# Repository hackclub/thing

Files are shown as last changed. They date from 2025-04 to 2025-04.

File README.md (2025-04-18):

<picture>
  <source media="(prefers-color-scheme: dark) and (max-width: 960px)" srcset="./thing.png">
  <source media="(prefers-color-scheme: dark) and (min-width: 961px)" width="50%" srcset="./thing.png">

  <source media="(prefers-color-scheme: light) and (max-width: 960px)" srcset="./thing-light.png">
  <source media="(prefers-color-scheme: light) and (min-width: 961px)" width="50%" srcset="./thing-light.png">

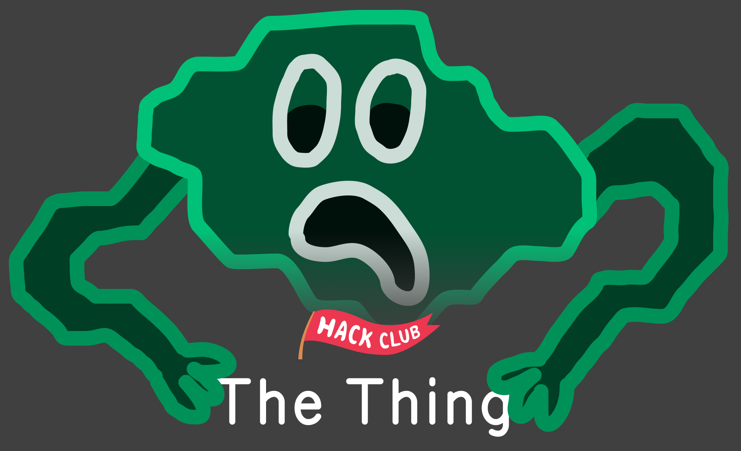
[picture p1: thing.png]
The thing
  
</picture>

Hey! Welcome to **The Thing**!

## Hey, what is this thing?
Have you seen those 80-part Swiss Army knives? I want us to make a PCB with that level of esotericism; a sprawling, over-the-top monstrosity.

Many Hack Clubbers will add a tool or something to the same PCB consecutively, and at the end I'll get \~10 made and send them off to some people you may or may not have seen on YouTube...
(and if you find me at a hackathon and you've added a subsystem to the board you may end up with one too (prob limited to 1 or 2)).

It'll end when 100 subsystems have been added or nobody adds a component for a week. Happy hacking!

## Current thing:
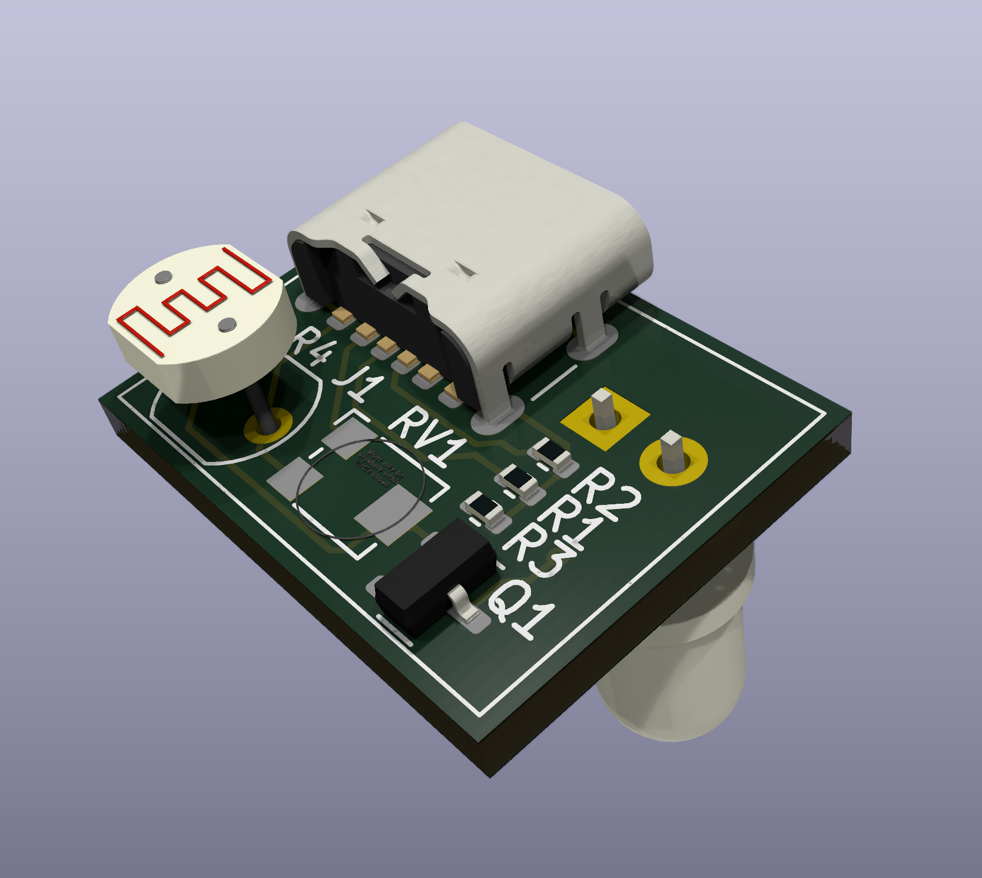
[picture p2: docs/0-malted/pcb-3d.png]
3D PCB


## How will it work?
* People will take turns adding their subsystem.
* Each person will get 2 days. If it's not merged after exactly 2 days, you'll be put at the back of the queue for another go and it'll be handed off to the next person. **I'll DM you a day or two before it's your turn to make sure you're ready. If you don't respond you might be skipped.**
* Merging requires me to be reasonably sure it'll work.

## What should my submission include?
* In the `/docs` directory, add a folder titled `IDX-USERNAME`, where `IDX` is your number in line, and `USERNAME` is your GitHub username.
  * For example, I'm the first person to go, so my folder is named `0-malted`.
  * In your folder, you'll need;
    * `doc.md`: Your writeup. Include detail about your subsystem! How you designed it, your calculations, tests, everything. Don't use an LLM, make it interesting, tell me a story!! :D
    * `pcb.png`: A screenshot of the PCB in Kicad's PCB editor, showing the entire PCB.
    * `pcb-3d.png`: Switch to View > 3D viewer and select "Render current view using raytracing". Again, we want to see the whole board!
    * `schematic.png`: A screenshot of the whole board's schematic.
    * `cad.png` **(OPTIONAL)**: If someone designs an enclosure or something (wink wink nudge nudge), show me a screenshot of it. You only need to do this if you've changed it.
    * `bom.csv`: Your bill of materials. Create and edit this manually. The price should be that of a single part (regardless of your `quantity`, **on the line item for 100 pieces**. It should be in USD without a dollar symbol.
      * For an exemplar BoM check mine out: `/docs/0-malted/bom.csv`. There's a template at `/docs/bom-template.csv`.
  * Make your schematic as complete as possible! When you double click your components you can add datasheets to help out others who might need to tie into your circuit or something in the future.

## Constraints
* Use Kicad `9.0.x`. Apparently, our project will be corrupted if we're on differing versions.
* Each BoM must not exceed $5 in parts. Assume 3D printing is free. If you have an especially cool idea I could be convinced to double it on a case-by-case basis :)
* Please strongly bias for parts in stock on Digikey.

## Tips
Finding parts can be tricky. Here's how I found the USB-C receptable I used in my circuit;
  1. Added a symbol to my schematic. I only wanted it for the 5V rail, so I found a symbol with the description "*USB Power-Only 6P Type-C Receptacle connector*". Seems okay.
  2. Opened the *footprint editor* and searched for "*usb c receptacle 6p*" (6P meaning it has 6 pins, which is minimal). I found a footprint named "*USB_C_Receptacle_GCT_USB4125-xx-x_6P_TopMnt_Horizontal*", which looked good. I liked the footprint because it had through-hole shield pins, meaning it would be less likely to be ripped off the board when pulling on it. The only other footprint which actually had 6 pins didn't have the through-hole shield.
  3. I searched on the internet for "*USB4125*". I found the [page from the manufacturer](https://gct.co/connector/usb4125) (GCT), which had links to Mouser and Digikey, amongst others. Heaven. It was slightly cheaper on Mouser so I went with that. It's comforting that it says *21230 In stock*.
  4. I double click on my component, click the library icon at the end of the "Footprint" table row, and searched for "*gct usb 4125*". Assigned it. Placed it on my PCB, and added it to my BoM! All done.

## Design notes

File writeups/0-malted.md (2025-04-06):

My subsystem is a nightlight that turns an LED on when an LDR (light-dependent resistor) detects it's dark. It's powered via a USB-C 5v rail.

When it's light, the resistance of the LDR is low, meaning the voltage at the base of the transistor is low, so the transistor is switched off, meaning the LED is not lit.
When it's dark, the resistance of the LDR is high, meaning the voltage at the base of the transistor is high, so the transistor switches on, allowing current to flow from the collector to emmitter, turning it on, allowing current to flow through the LED, through R3 to ground, lighting it up.

---

Alex sent me [this](https://cdn.sparkfun.com/datasheets/Sensors/LightImaging/SEN-09088.pdf) datasheet for the GL5528 LDR so that's what I'm going to work off - it's very generic. I'm also using a generic BJT NPM (Mouser has ~200k of [these](https://www.mouser.com/datasheet/2/308/BC550_D-1802078.pdf) in stock so that's what I'll go off, although none of the following is specific to this component.)

I don't know how much 100 lux or 1 lux is, but going by the diagram I'm going to assume that 100 lux is "bright" and 1 lux is "dark".
This means that when it's bright, the LDR will have a resistance of ~3kΩ, and when it's dark the LDR will have a resistance of 70kΩ.

When it's light, I want the LED to be off. This means the transistor must be off, meaning Vb must be < 0.7V.
So, using the voltage divider equation `Vout = R2 / (R1 + R2) * Vin`, and a voltage under 0.7V, say, 0.2V as our Vbe target, we calculate R1 to be 72kΩ, as shown below.

```
0.2 = 3k / (R1 + 3k) * 5
0.04 = 3k / (R1 + 3k)
0.04 * R1 + 120 = 3k
0.04 * R1 = 2.88k
R1 = 2.88k / 0.04
R1 = 72k
```

Great. Now, let's check to make sure that when it's dark, Vbe will be > 0.7V by plugging 72kΩ into R1 (keeping in mind R2 is now 70kΩ);

```
Vout = 70k / (72k + 70k) * 5
Vout ~= 2.5V
```

Yay! The output of our voltage divider is > 0.7V, so it's going to switch the transistor on, meaning the LED will light up.

Now let's calculate R3. Without it, we'd be dumping 5V across our poor little LED.

I've selected a [nice little amber LED to use](https://www.mouser.com/datasheet/2/678/av02-1532en_ds_hlmp-wl02_2014-08-20-1827901.pdf). Nora said amber makes for a good nightlight colour. The datasheet says it has a 2.02V drop. BJTs typically drop 0.2V. So, the voltage our R3 needs to drop is (5 - (2.02 + 0.2)) = 2.78V`.

Our LED datasheet says the LED should typically be operated between 10mA and 30mA, so let's pick 20mA. This means R3 needs to be the following;

```
V = IR
2.78 = 0.02 * R
R = 2.78 / 0.02
R = 139
```

R3 needs to be 139Ω. There's no 139Ω resistor in the [E24 series](https://asenergi.com/pdf/resistors/standard-resistor-values-e24.pdf) so I'll pick a 150Ω resistor which is close enough!

---

Footnote, it's been so long since I've done calculations like this that I forgot to make sure Ic is high enough to saturate the transistor. It's *JUST* about there. It's not going to kneecap the subsystem as far as I can tell so I won't rejig the voltage divider.

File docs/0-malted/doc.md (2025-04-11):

My subsystem is a nightlight that turns an LED on when an LDR (light-dependent resistor) detects it's dark. It's powered via a USB-C 5v rail.

When it's light, the resistance of the LDR is low, meaning the voltage at the base of the transistor is low, so the transistor is switched off, meaning the LED is not lit.
When it's dark, the resistance of the LDR is high, meaning the voltage at the base of the transistor is high, so the transistor switches on, allowing current to flow from the collector to emmitter, turning it on, allowing current to flow through the LED, through R<sub>3</sub> to ground, lighting it up.

---

Firstly, I need a power source. It's 2025, so I want to plug in a USB-C cable. I looked for a while and found this. It needs 2 5k1Ω resistors on the *CC* lines, which are for negotiating power. If you wanted to get serious you can negotiate up to like 20V and >3A IIRC but for this 5V is all I want. [A Hack Club alum—Hugo—made an amazing reference guide for USB-C power lines a couple of years ago](https://www.hugohu.me/media/USB-C.Primer.pdf), in which it says to use 5100Ω resistors on both CC1 and CC2 lines to be compatible with fancy USB-C cables and bricks. [Here's the 5k1Ω resistor I chose.](https://www.digikey.com/en/products/detail/yageo/RC0402FR-075K1L/726624), and here's the USB-C receptable I found! I wrote my thought process leading to finding this specific component at the bottom of the readme.

I searched for an LDR on Digikey and found the [PDV-P8103](https://www.digikey.com/en/products/detail/advanced-photonix/PDV-P8103/480610). Generic photoresistor. Great! According to the datasheet, is resistance is 0.5MΩ in the dark and 16k-33kΩ in the light.

> I originally tried to use an [NPN BJT](https://en.wikipedia.org/wiki/Bipolar_junction_transistor) (in writing this doc I kept typing NPM - the rot consumes) that looked good, but I found out that my base current would be too low to drive my LED because of the high voltage divider resistor values. I switched to a MOSFET.

I found a MOSFET on Digikey that has a footprint in Kicad; the [T2N7002AK](https://www.digikey.com/en/products/detail/toshiba-semiconductor-and-storage/T2N7002AK-LM/5298028). Looking at [the datasheet](https://toshiba.semicon-storage.com/info/docget.jsp?did=29712&prodName=T2N7002AK), we can tell V<sub>GSₜₕ</sub>—or the voltage drop between the gate and the source when the MOSFET switches—is between 1.1V and 2.1V. Normally, I would calculate the resistor value to be exactly correct. But since I can't know how bright users' rooms will be at night, I'm going to opt for a trimmer potentiometer so they can calibrate it themselves. 100kΩ max should be enough. The trimpot I'm going to use is the [TC33X-2-104E](https://www.digikey.com/en/products/detail/bourns-inc/TC33X-2-104E/612859).

Now let's calculate the value for R<sub>3</sub>. Without it, we'd be dumping ~5V across our little LED.

According to the MOSFET's datasheet, the drop across the drain and source (V<sub>DS</sub>) looks like ~100mV when I<sub>D</sub> is ~20mA and V<sub>GS</sub> is ~4V. The graph resolution down there is quite low so this is approximate but since it's proportionally such a small voltage it doesn't matter too much anyway.
Id-Vds graph for the T2N7002AK MOSFET

I've selected a [nice little amber LED to use](https://www.mouser.com/datasheet/2/678/av02-1532en_ds_hlmp-wl02_2014-08-20-1827901.pdf). Nora said amber makes for a good nightlight colour. The datasheet says it has a 2.02V drop. So, combined with the MOSFET's V<sub>DS</sub>, the voltage our R<sub>3</sub> needs to drop is (5 - (2.02 + 0.1)) = 2.88V`.

Our LED datasheet says the LED should typically be operated between 10mA and 30mA, so let's pick 20mA. This means R<sub>3</sub> needs to be the following;

```
V = IR
2.88 = 0.02 * R
R = 2.88 / 0.02
R = 144
```

R<sub>3</sub> needs to be 144Ω. There's no 144Ω resistor in the [E24 series](https://asenergi.com/pdf/resistors/standard-resistor-values-e24.pdf) so I'll pick a 150Ω resistor which is close enough!

I'm picking a surface-mounted resistor with a power rating of 1/16W, which is less than what I could dump across a through-hole. Let's check to see if how I want to use it would be in spec. This can be checked with the power law.

```
P = IV
1/16 = 20mA * V
V = (1/16) / 0.02
V ‎ = 3.125
```

So, with the current load, the resistor can drop a max of 3.125V. This is okay, because in its current configuration it's only dropping 2.88V.

The total of my BoM is only ~$1.38 :) nice

> P.S. I'm pretty proud I got my pcb traced in a single layer! Routing everything again and again was very theraputic.

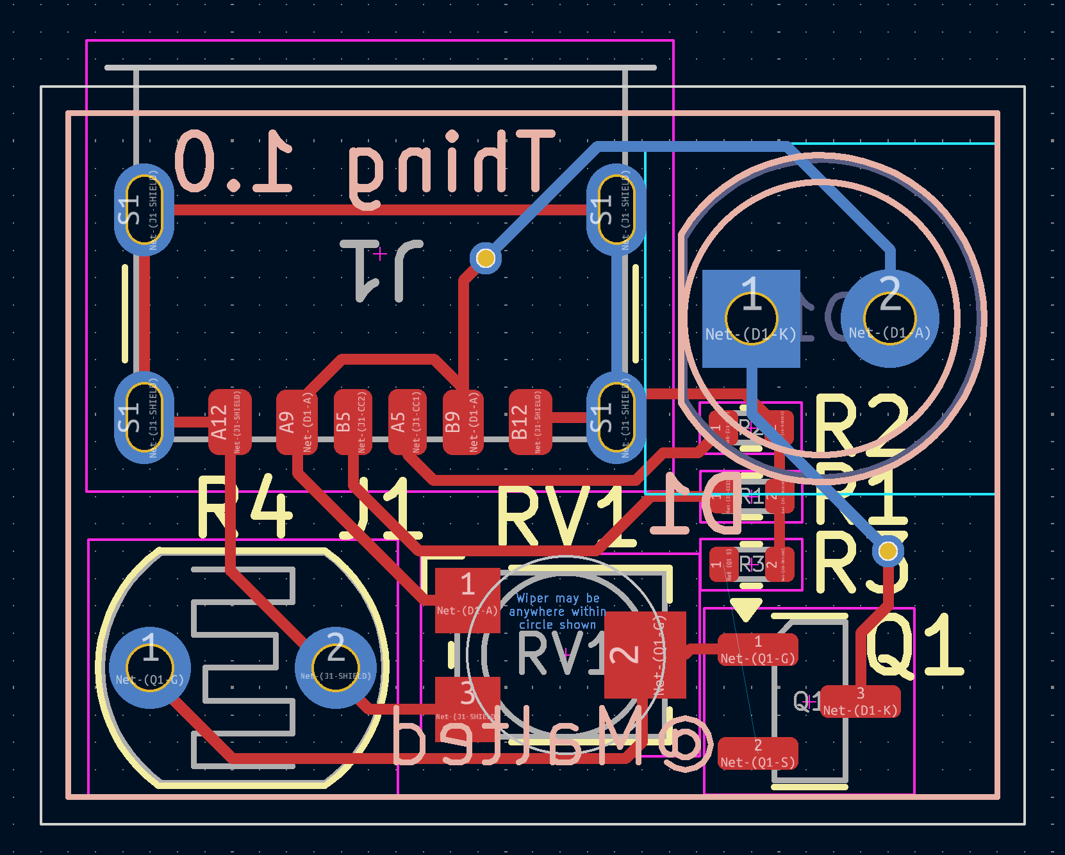
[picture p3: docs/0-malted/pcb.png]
PCB

3D PCB
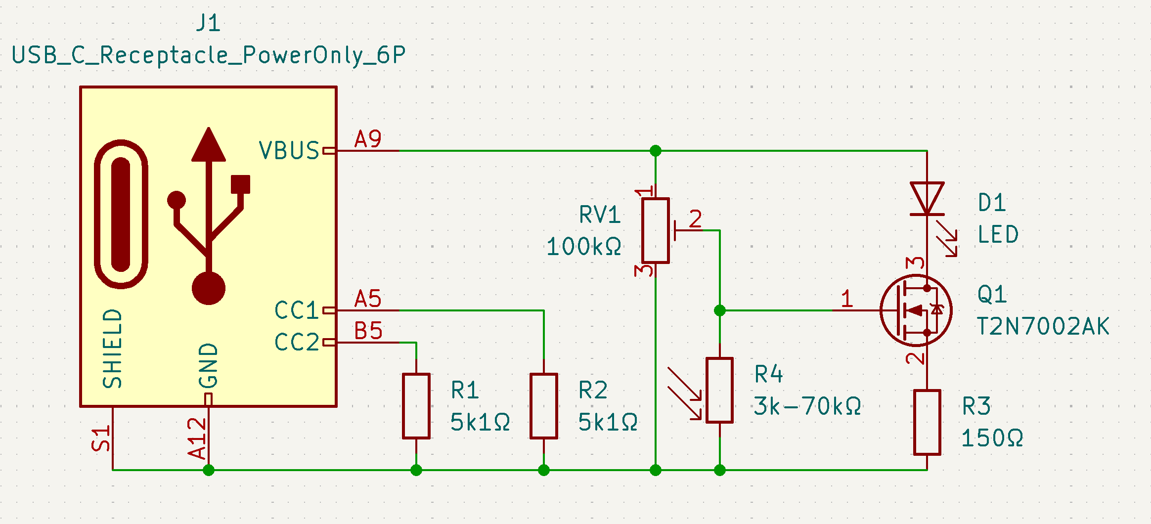
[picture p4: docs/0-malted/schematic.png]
Schematic


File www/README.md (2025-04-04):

# sv

Everything you need to build a Svelte project, powered by [`sv`](https://github.com/sveltejs/cli).

## Creating a project

If you're seeing this, you've probably already done this step. Congrats!

```bash
# create a new project in the current directory
npx sv create

# create a new project in my-app
npx sv create my-app
```

## Developing

Once you've created a project and installed dependencies with `npm install` (or `pnpm install` or `yarn`), start a development server:

```bash
npm run dev

# or start the server and open the app in a new browser tab
npm run dev -- --open
```

## Building

To create a production version of your app:

```bash
npm run build
```

You can preview the production build with `npm run preview`.

> To deploy your app, you may need to install an [adapter](https://svelte.dev/docs/kit/adapters) for your target environment.

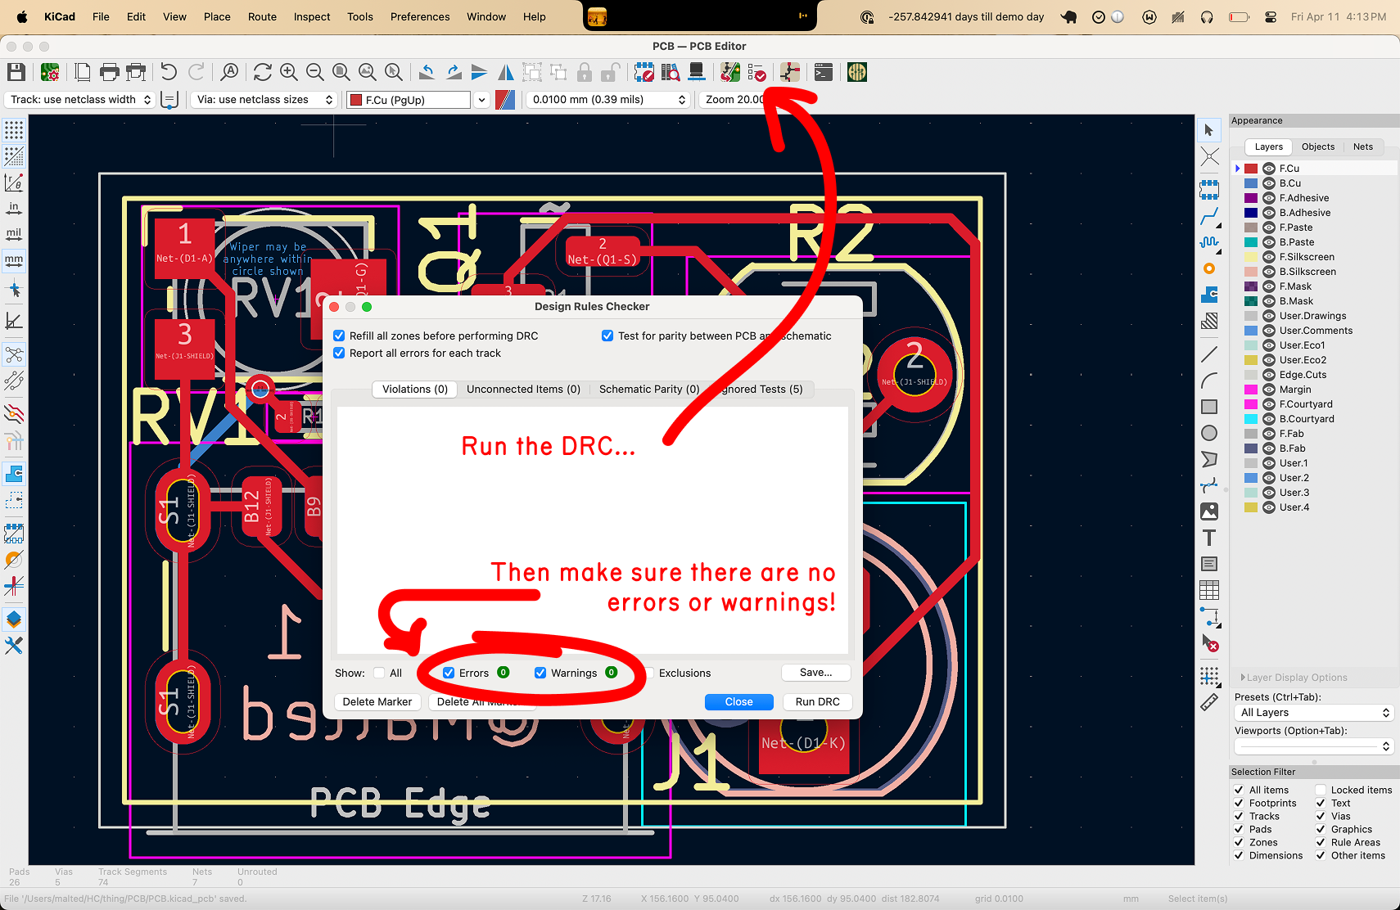
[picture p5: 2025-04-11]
DRC.png

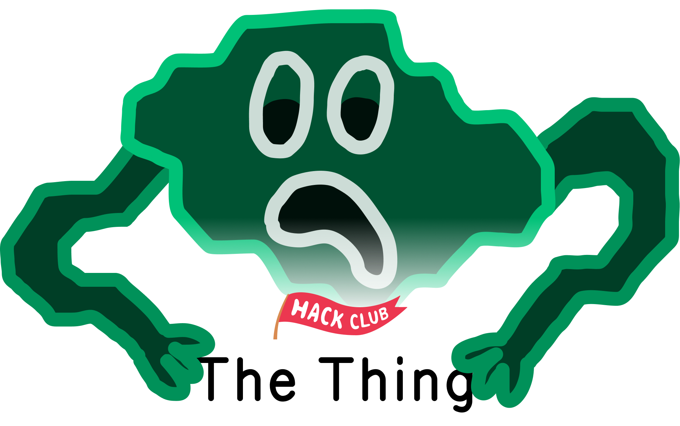
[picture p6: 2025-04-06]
thing-light.png

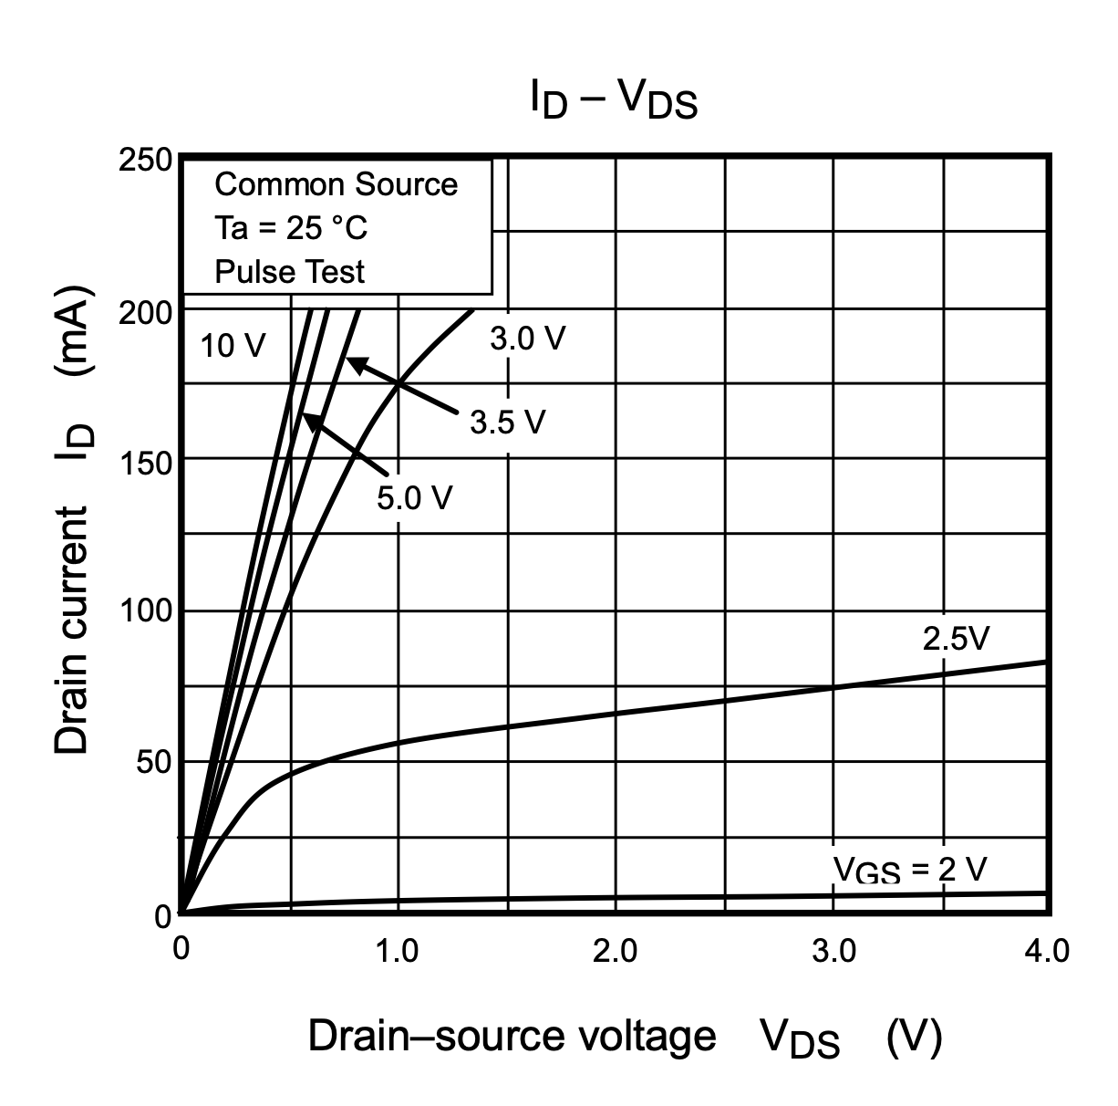
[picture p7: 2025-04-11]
docs/0-malted/assets/T2N7002AK-Id-Vds.png

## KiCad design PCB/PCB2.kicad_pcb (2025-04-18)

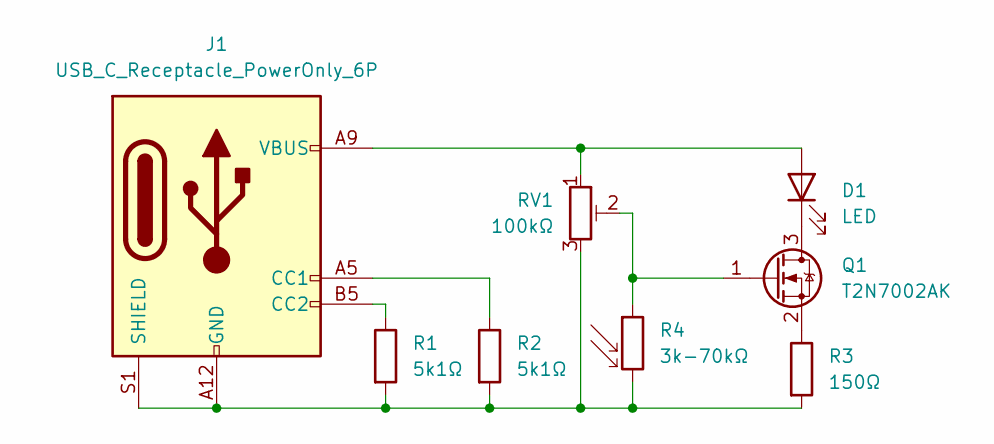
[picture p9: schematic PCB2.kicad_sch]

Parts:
D1: LED; LED_D5.0mm_Clear
J1: USB_C_Receptacle_PowerOnly_6P; USB_C_Receptacle_GCT_USB4125-xx-x-0190_6P_TopMnt_Horizontal
Q1: T2N7002AK; SOT-23
R1, R2: 5k1Ω; R_0402_1005Metric
R3: 150Ω; R_0402_1005Metric
R4: 3k-70kΩ; R_LDR_5.1x4.3mm_P3.4mm_Vertical
RV1: 100kΩ; Potentiometer_Bourns_TC33X_Vertical

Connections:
unnamed: D1.2 (A), J1.A9 (VBUS), J1.B9 (VBUS), RV1.1
unnamed: D1.1 (K), Q1.3 (D)
unnamed: J1.A5 (CC1), R2.1
unnamed: J1.B5 (CC2), R1.1
unnamed: J1.A12 (GND), J1.B12 (GND), J1.S1 (SHIELD), R1.2, R2.2, R3.2, R4.2, RV1.3
unnamed: Q1.1 (G), R4.1, RV1.2
unnamed: Q1.2 (S), R3.1

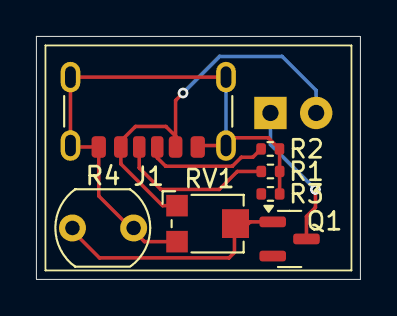
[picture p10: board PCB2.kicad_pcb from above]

Board: 2 copper layers, 18.0 x 13.5 mm, 8 parts (1 on the bottom side), 7 nets.

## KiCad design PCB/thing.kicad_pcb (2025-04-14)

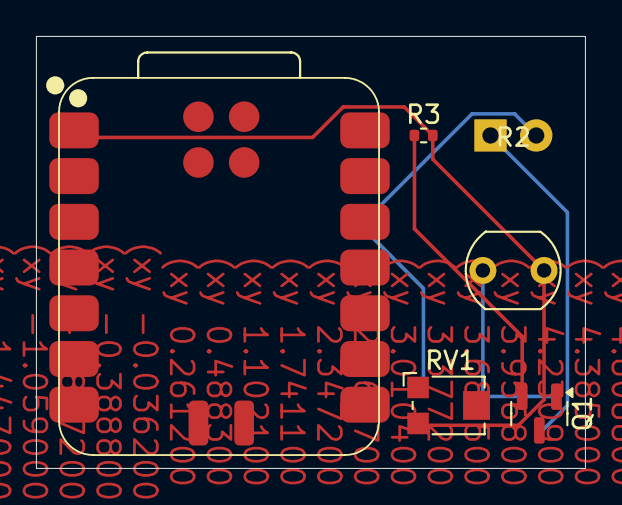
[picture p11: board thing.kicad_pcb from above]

Board: 2 copper layers, 30.5 x 24.0 mm, 6 parts (1 on the bottom side), 5 nets.

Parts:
D1: LED; LED_D5.0mm_Clear
Q1: SOT-23
R2: 3k-70kΩ; R_LDR_5.1x4.3mm_P3.4mm_Vertical
R3: 68Ω; R_0402_1005Metric
RV1: 100kΩ; Potentiometer_Bourns_TC33X_Vertical
U1: Seeed Studio XIAO SAMD21; XIAO-RP2040-SMD

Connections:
unnamed: D1.2 (A), RV1.1, U1.12 (3V3)
unnamed: D1.1 (K), Q1.3 (D)
unnamed: Q1.1 (G), R2.1, RV1.2
unnamed: Q1.2 (S), R3.1
unnamed: R2.2, R3.2, RV1.3, U1.1 (PA02_A0_D0)

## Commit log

2025-04-05 Create PCB
    [PCB.kicad_pcb, PCB.kicad_sch]
2025-04-05 Route PCB
    [PCB.kicad_pcb]
2025-04-06 Add writeups
    [PCB.kicad_sch]
2025-04-06 Clean up board
    [PCB.kicad_pcb, PCB.kicad_sch, freerouting.dsn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]
2025-04-11 Reroute PCB
    [PCB.kicad_sch]
2025-04-11 Finish documentation
    [bom.csv]
2025-04-11 Add bill of materials template
    [bom-template.csv]
2025-04-11 Filter emails out and make sure the slack ID is valid
2025-04-11 Add 5k1 CC resistors to negotiate 5V
    [PCB.kicad_sch]
2025-04-11 Document CC resistors
2025-04-11 Add and route CC 5k1Ω resistors
    [PCB.kicad_pcb, PCB.kicad_sch]
2025-04-14 Tie all xiao gnd outs to ground
    [thing.kicad_sch]
2025-04-14 Clean up schematic
    [thing.kicad_sch]
2025-04-14 Revert to malted's PCB
    [PCB.kicad_pcb, PCB.kicad_sch, bom.csv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]
2025-04-18 Rebuilt PCB
    [PCB.kicad_pcb, PCB2.kicad_pcb, PCB2.kicad_sch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]
2025-04-18 Move LED to back of PCB
    [PCB2.kicad_pcb]
2025-04-18 Add instructions in PCB file
    [PCB2.kicad_pcb]
2025-04-18 Add the current thing to the readme
    [PCB2.kicad_pcb]
